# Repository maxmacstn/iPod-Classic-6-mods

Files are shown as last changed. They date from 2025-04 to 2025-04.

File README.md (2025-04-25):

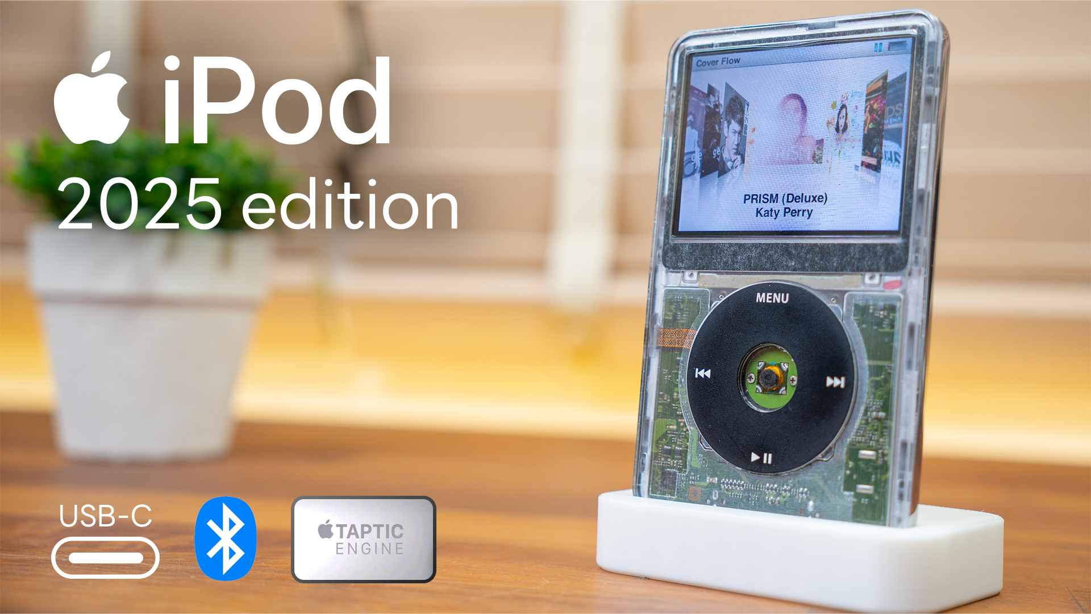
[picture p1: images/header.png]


# iPod Classic Mods
My attempt at modernizing the iPod Classic (6th generation) includes the following:

- [USB-C Mod](https://github.com/maxmacstn/iPod-Classic-6-mods/tree/main/Mods/USB-C) – Converts the 30-pin dock connector to a USB-C interface.

- [Bluetooth Audio Mod](https://github.com/maxmacstn/iPod-Classic-6-mods/tree/main/Mods/ESP32-Bluetooth-Audio) – Enables audio transmission to headphones or speakers via Bluetooth, with playback control.

- Taptic Engine – Replaces the clicking sound (from the buzzer) with haptic feedback. There are a bunch of videos out there on how to do this mod, so I haven’t included it in this repo. I used a Taptic Engine from an iPhone 11 Plus. It's small and provides a nice, firm vibration.

Click the link above to see the details.

### Video : [**Youtube (TH)**](https://youtu.be/0jGxkwJ26Vk)

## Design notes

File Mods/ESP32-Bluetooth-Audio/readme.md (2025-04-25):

# Bluetooth Audio Mod
The iPod Classic does not have any built-in radio. The only way to listen to music is by physically connecting to the 3.5mm audio jack or the dock connector.

For the Bluetooth mod, people usually use off-the-shelf Bluetooth transmitter modules connected to the headphone output. This method works, but the audio quality isn't the best, and you can't control playback via Bluetooth headphones or speakers.

Instead of using an off-the-shelf Bluetooth transmitter module, I made my own Bluetooth board for this purpose. The main controller is an ESP32.

## Version 1 - Music via I2S
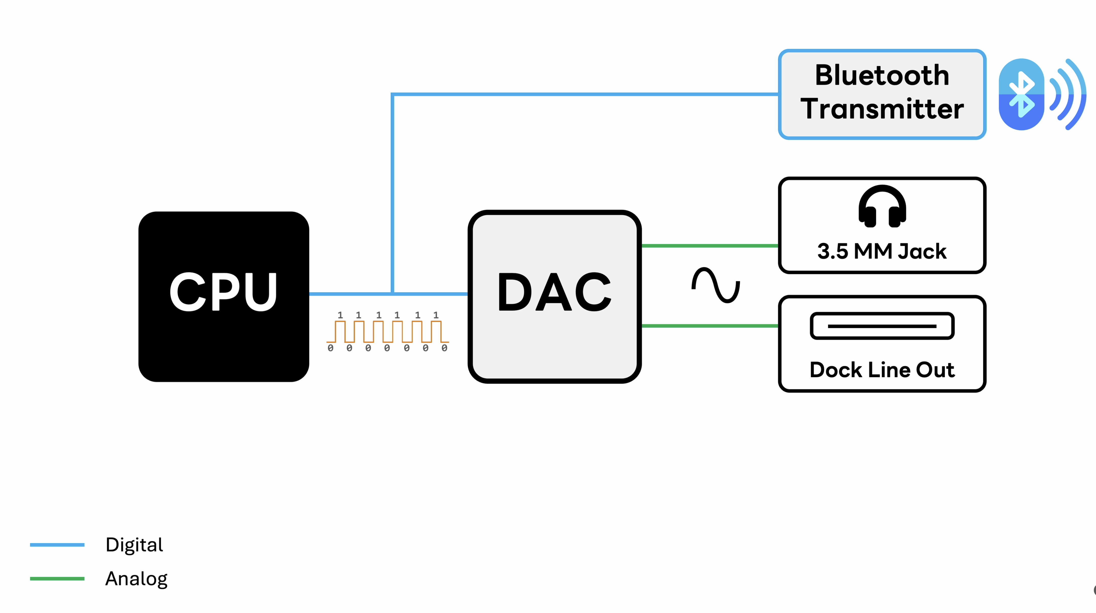
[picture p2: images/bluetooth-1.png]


When the iPod produces sound, it sends a digital audio signal from the CPU to the DAC via the I2S protocol. The digital signal is then converted into an analog signal, which is the sound we hear through headphones. To preserve the original sound quality, tapping into the I2S signal is the way to go.

I didn’t coin the idea of hijacking the I2S signal from the iPod. I found [this really cool project](https://github.com/lemonjesus/iPodBluetooth) by @lemonjesus, where he successfully did this with his iPod Nano 3rd gen. I wanted to apply this concept to my iPod Classic 6th gen as well.

From my research, the iPod Classic 6th gen uses a DAC from Cirrus Logic — allegedly the CS42L55. I checked the pinout from the datasheet, and it matches.

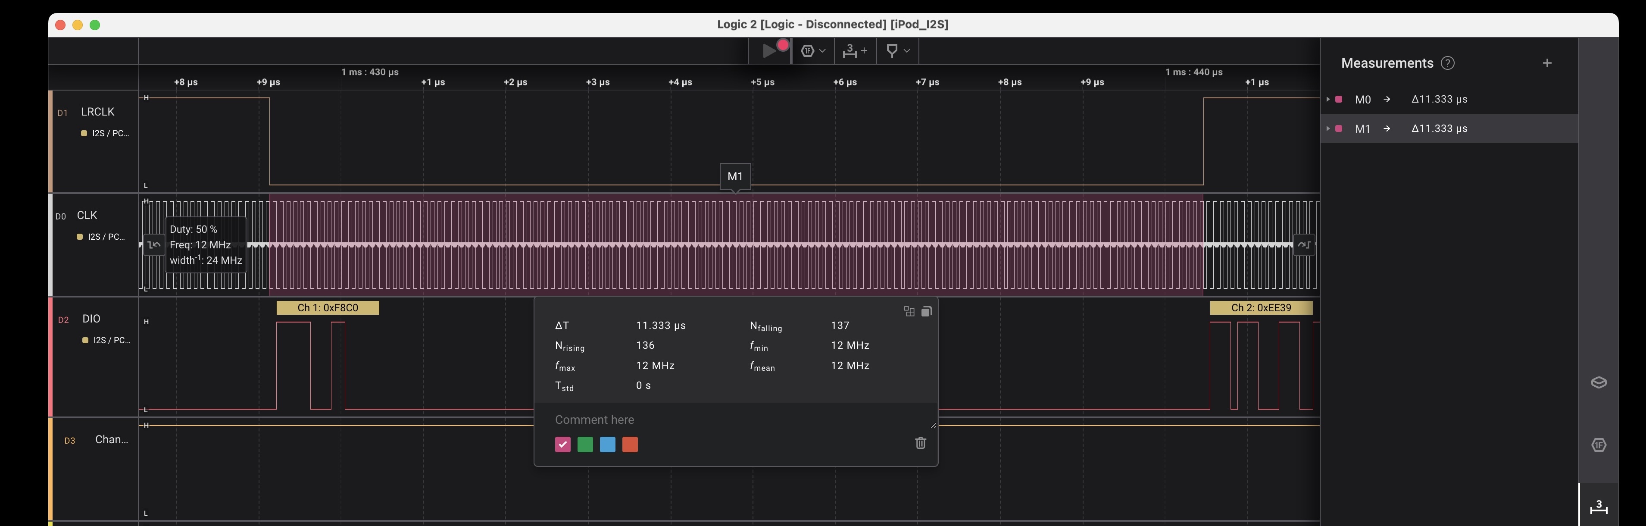
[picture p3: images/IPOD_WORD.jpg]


Long story short, this version of the iPod uses a not-so-standard I2S protocol. While the signal is technically I2S, the BCLK line runs at a very high speed (12 MHz) and also acts as MCLK. The word length is also not 16-bit. After months of trying, I wasn’t able to get it working properly with the ESP32. I gave up using I2S as the audio source from the iPod Classic.

However, I bought a Nano 3rd gen, and my Bluetooth board works as expected with it.

## Version 2 - Music via Line Out
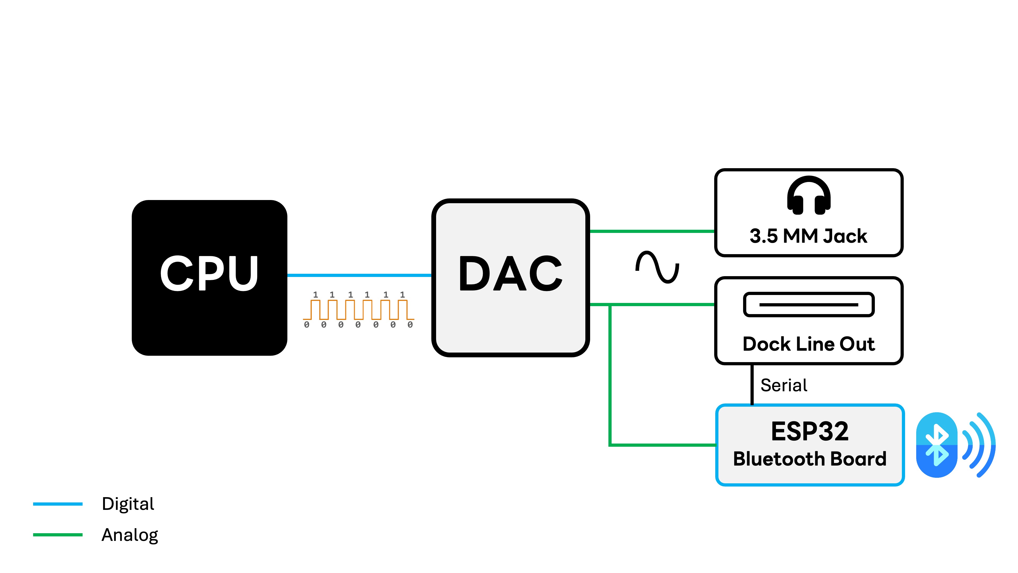
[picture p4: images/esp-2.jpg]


### Design 
Instead of using I2S, I used the line-out signal from the dock connector. The analog audio signal from the line-out is converted back to digital I2S using an ADC—specifically the PCM1860.

For playback control, external accessories can control the iPod via the dock connector using a serial protocol. There are a bunch of [examples online](https://github.com/finsprings/arduinaap). I’ve already prepared breakout pads for both the line-out and serial connections from the USB-C mod.

### Sound Quality
Definitely not as good as the original source since the audio goes through double conversion. I would say the sound quality is neither great nor terrible — it's acceptable. When listening through high-quality headphones or speakers, I can hear very subtle digital noise from interference. I even tried connecting the line-out directly from the DAC IC, but the noise was still there. So, I applied a simple filter: if the signal amplitude is very low, I set it to zero. I think this is good enough. The noise is mostly inaudible when music is playing.

### Power
I soldered the VBATT line after it passes through the power management IC. As a result, it's powered off along with the iPod. However, it doesn’t sleep when the iPod sleeps. So I implemented a check on the audio signal — if it's silent for five minutes, the Bluetooth board goes into deep sleep. There is still a small current draw, which drains the iPod’s battery in a few days. Initially, I used the 1.8V bus to enable the ESP32's power regulator, but that method stopped working for some reason, and I’ve been too lazy to fix it.

The original battery gives around 2 hours of Bluetooth music playback. This is just a proof of concept, and the battery life isn’t great.

### Bluetooth usage
I intended to not modify any sofware on the iPod, so how I could pair bluetooth device from the iPod, here's the step.
1. Restart the iPod by holding `SELECT` + `MENU`. This cuts off the power to the iPod, as well as the bluetooth board.
2. Once connected to the power, the bluetooth board starts discovering bluetooth audio device, then connected to the nearest (strongest signal) one.
3. Enjoy the music via bluetooth.
4. If there's no audio for 5 minutes, the Bluetooth board (ESP32) goes into deep sleep—until power is cut and reconnected.

### Signal
The iPod Classic has a metal front and back plate, which basically makes it a Faraday cage — signal can’t pass through easily. I removed the metal support underneath the display, which allows the signal to pass through a bit, but the range is still very limited (<1m). This could be easily fixed by 3D printing a plastic back cover—but that’s for later.

***TBC***

### Images



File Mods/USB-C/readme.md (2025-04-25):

# USB-C Mod
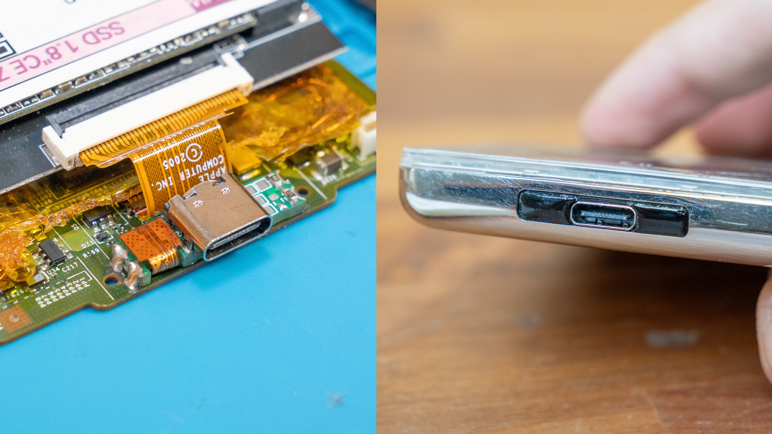
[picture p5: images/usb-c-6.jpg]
image info


## Why
As we know, the 30-pin dock connector is an outdated interface that's no longer commonly used. This mod replaces the dock connector with a USB-C port. Keep in mind that you'll lose support for other dock connector features and won't be able to use 30-pin accessories anymore. For me, the convenience of USB-C makes it a no-brainer.

## Design

The dock connector is ancient. How it works is each pin has a specific purpose, e.g. USB, FireWire, line out, serial, etc. Therefore, it has many pins. What I did was tap into the USB D+, D−, VCC, and GND from the dock connector and connect them to a USB-C port. Seems simple, doesn't it?

However, the depth of the USB-C port is longer than the 30-pin dock connector. The PCB part that holds the USB-C port sits over the dock connector solder pads. What I did was create two parts: a solid PCB and a flexible PCB. The solid PCB holds the USB-C connector as well as attaches the PCB itself to the iPod's circuit board. The flexible PCB, aka FPC, connects the corresponding pins from the dock connector solder pads to the solid PCB. The FPC bends 180° to connect to the PCB using a Molex mezzanine connector. Don't forget to put some tape on the bottom of the PCB to avoid shorting to the dock connector pads.

The PCB includes three 0603 resistors—two for enabling charging with USB-C PD adapters, and one (optional) for iPod accessory identification. Additionally, there are four soldering pads connected to the dock connector: Line_L, Line_R (for audio line out), and TX, RX (for serial communication). These are used for other mods, like the Bluetooth audio mod, which I used it.

Finally, the port bezel, attached to the iPod’s back cover, had to be replaced. I designed a new bezel for the USB-C port and 3D printed it using an FDM printer. After some sanding and painting, it now has a nice glossy finish.

## How hard if I want one?
I am not going to sell it. I have provided all the files, including the KiCad project, Gerber files, bill of materials, as well as the 3D file in this repository. If you dare to solder these tiny parts, you’ll need to fabricate them yourself through a PCB manufacturer of your choice.

I'm not a microsoldering expert, but I would say I have intermediate soldering skills. It's still quite challenging. For me, the hardest part was soldering the mezzanine connectors.

## Conclusion
USB-C works perfectly fine. It connects to the computer as well as the car's infotainment system—no issues so far. The charging function and speed are the same as the original. The Apple original charger is still needed for the iPod to display the charging icon, or you can charge via a PC.

## Images

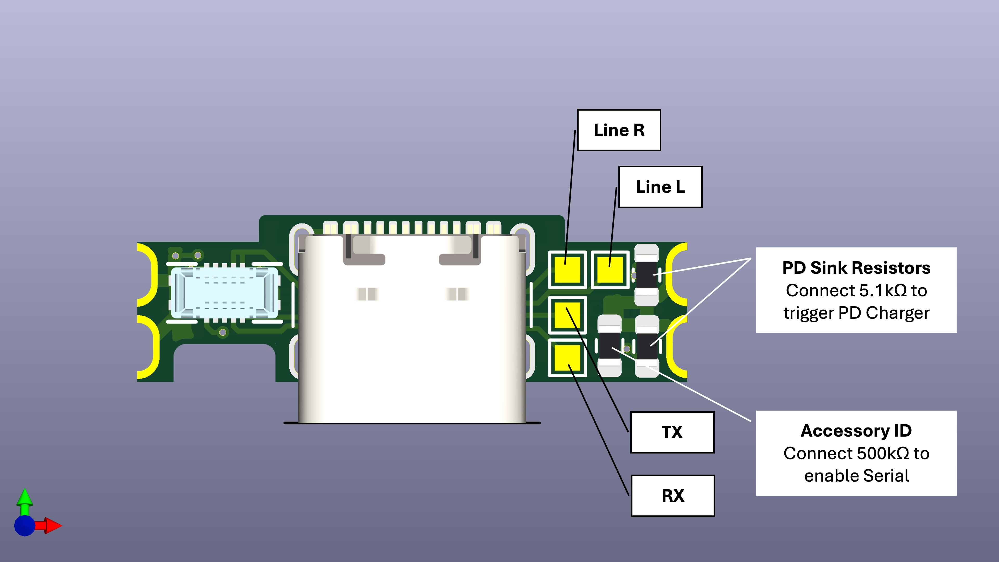
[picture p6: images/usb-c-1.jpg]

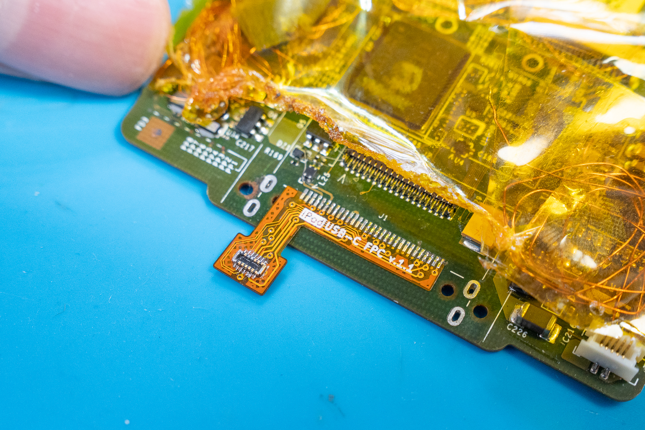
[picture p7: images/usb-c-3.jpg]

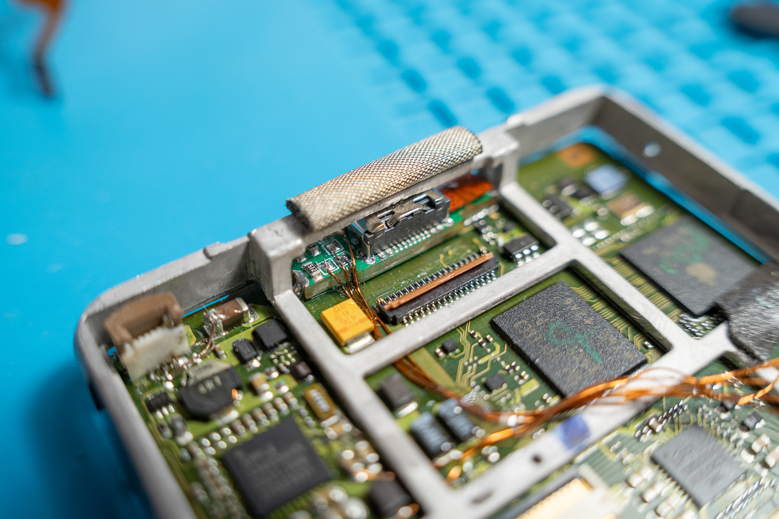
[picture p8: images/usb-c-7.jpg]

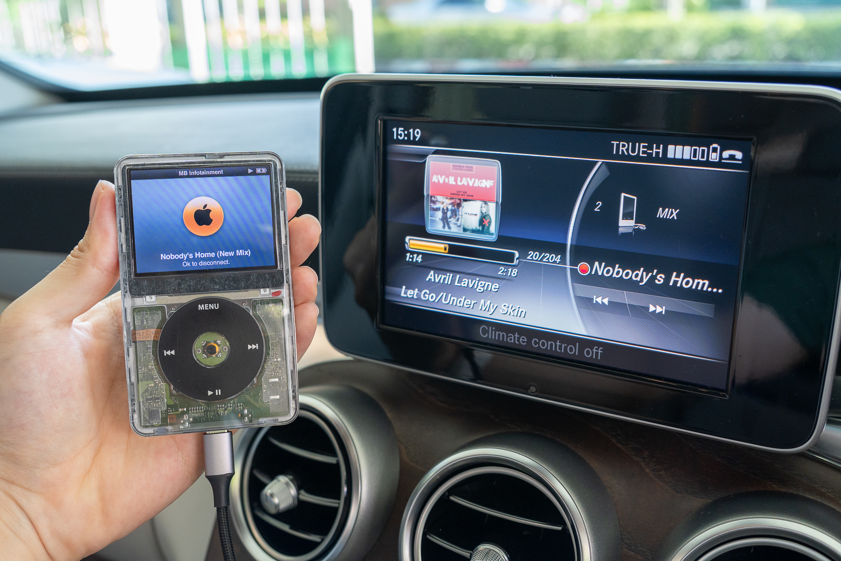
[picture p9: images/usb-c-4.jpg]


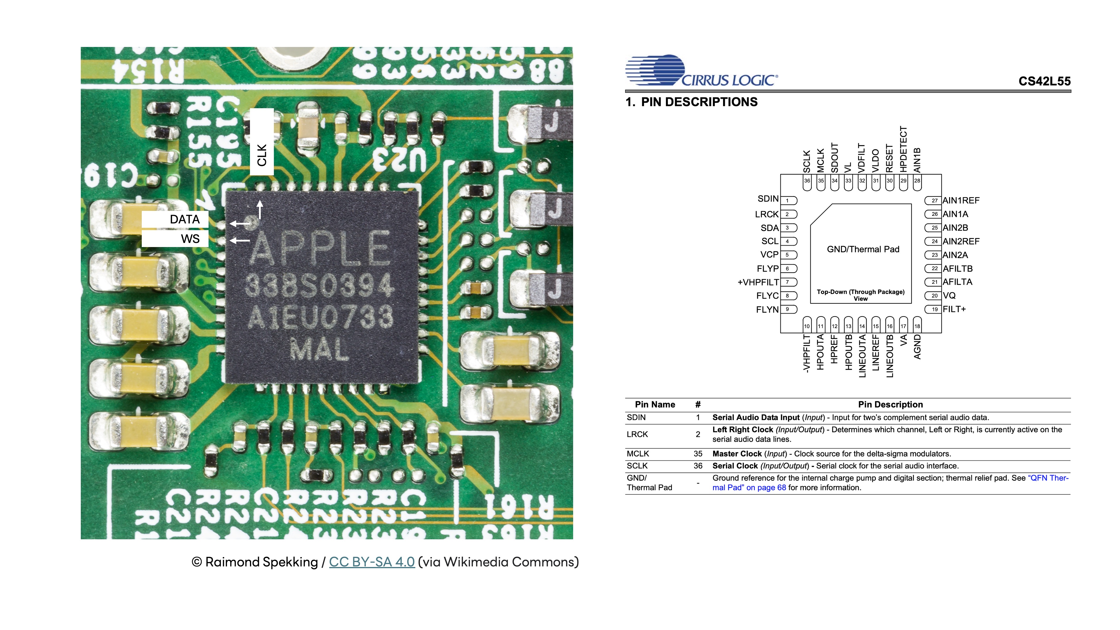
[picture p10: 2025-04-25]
images/ipod_i2s_pinout.jpg

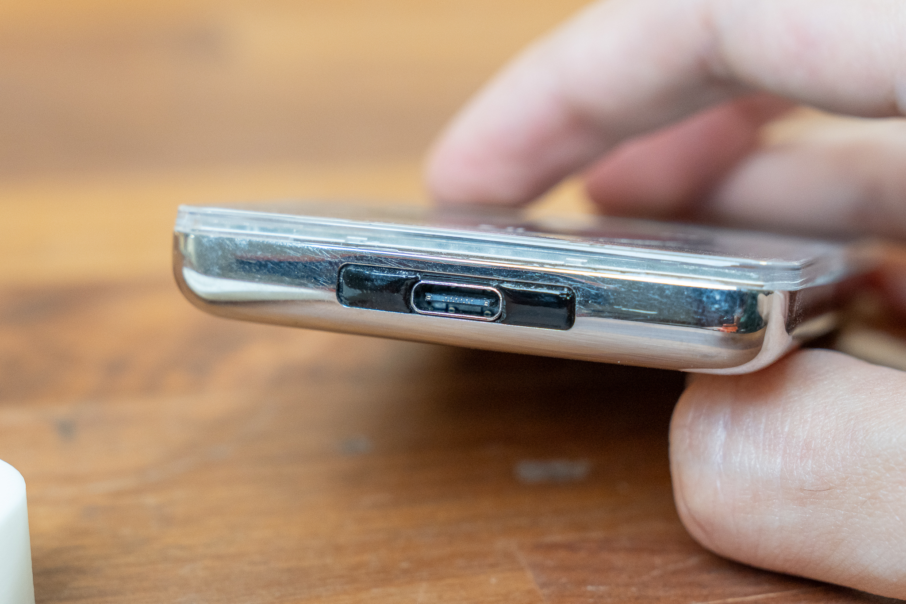
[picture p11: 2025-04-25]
images/usb-c-2.jpg

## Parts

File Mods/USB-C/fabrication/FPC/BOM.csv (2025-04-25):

Reference | Value | Datasheet | Footprint | Qty | DNP
J2 | ~ | https://www.molex.com/en-us/products/part-detail/5050701022?display=pdf | Connector_Molex:MOLEX_505070_1022 | 1

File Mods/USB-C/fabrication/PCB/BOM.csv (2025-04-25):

Reference | Value | Datasheet | Footprint | Qty | DNP
J1 | 5052701012 | 5052701012 | Connector_Molex:MOLEX_505270_1012 | 1
J2 | USB_C_Receptacle_USB2.0_16P | https://www.usb.org/sites/default/files/documents/usb_type-c.zip | Connector_USB:USB_C_Receptacle_GCT_USB4105-xx-A_16P_TopMnt_Horizontal | 1
R1,R2 | 5.1K | ~ | Resistor_SMD:R_0603_1608Metric | 2
R3 | 500K | ~ | Resistor_SMD:R_0603_1608Metric | 1
TP1 | TX | ~ | TestPoint:TestPoint_Pad_1.0x1.0mm | 1
TP2,TP3,TP4 | RX | ~ | TestPoint:TestPoint_Pad_1.0x1.0mm | 3

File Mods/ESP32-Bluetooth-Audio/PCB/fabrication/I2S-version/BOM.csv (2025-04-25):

Comment | Designator | Footprint | LCSC
0.1uF | C1,C3,C4 | Capacitor_SMD:C_0402_1005Metric | C110251
22uF | C2 | Capacitor_SMD:C_0805_2012Metric | C5674
LED | D1 | LED_SMD:LED_0603_1608Metric | C434421
Conn_01x09_Socket | J1 | Connector_JST:JST_ZH_S9B-ZR-SM4A-TF_1x09-1MP_P1.50mm_Horizontal
Conn_01x05_Socket | J2 | Connector_PinHeader_2.54mm:PinHeader_1x05_P2.54mm_Vertical
10K | R1 | Resistor_SMD:R_0402_1005Metric | C60490
1K | R2 | Resistor_SMD:R_0402_1005Metric | C106235
TLV76733DRVx | U1 | Package_SON:WSON-6-1EP_2x2mm_P0.65mm_EP1x1.6mm_ThermalVias | C2848334
ESP32-WROOM-E | U2 | PCM_Espressif:ESP32-WROOM-32E | C701341
TXU0104RUTR | U3 | Package_DFN_QFN:Texas_R-PUQFN-N12 | C5187176

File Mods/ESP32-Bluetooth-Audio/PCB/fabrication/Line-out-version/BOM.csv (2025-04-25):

Comment | Designator | Footprint | LCSC
0.1uF | C1 | Capacitor_SMD:C_0402_1005Metric | C110251
22uF | C2 | Capacitor_SMD:C_0805_2012Metric | C5674
10uF | C3,C4 | Capacitor_SMD:C_0805_2012Metric | C5674
2.2uF | C5,C6 | Capacitor_SMD:C_0402_1005Metric | C12530
15pF | C7,C8 | Capacitor_SMD:C_0402_1005Metric | C106997
LED | D1 | LED_SMD:LED_0603_1608Metric | C434421
Conn_01x09_Socket | J1 | Connector_JST:JST_ZH_S9B-ZR-SM4A-TF_1x09-1MP_P1.50mm_Horizontal
Conn_01x06_Pin | J2 | Connector_PinHeader_2.54mm:PinHeader_1x06_P2.54mm_Vertical
10K | R1 | Resistor_SMD:R_0402_1005Metric | C60490
1K | R2 | Resistor_SMD:R_0402_1005Metric | C106235
10K | RN1 | Resistor_SMD:R_Array_Convex_4x0603 | C29718
TLV76733DRVx | U1 | Package_SON:WSON-6-1EP_2x2mm_P0.65mm_EP1x1.6mm_ThermalVias | C2848334
ESP32-WROOM-E | U2 | PCM_Espressif:ESP32-WROOM-32E | C701341
PCM1860 | U3 | Package_SO:TSSOP-30_4.4x7.8mm_P0.5mm | C1520799
2N7002DW | U4 | Package_TO_SOT_SMD:SOT-363_SC-70-6 | C83571
Crystal_GND24 | Y2 | Crystal:Crystal_SMD_3225-4Pin_3.2x2.5mm | C19631429

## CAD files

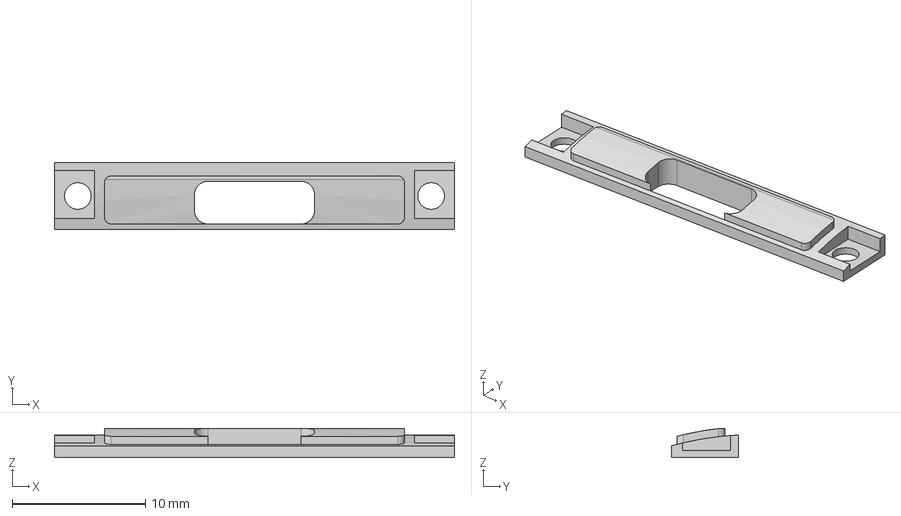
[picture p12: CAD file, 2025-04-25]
Mods/USB-C/fabrication/Port-bezel/ipod-usbc-cover-v3.step
30.0 x 5.00 x 2.20 mm

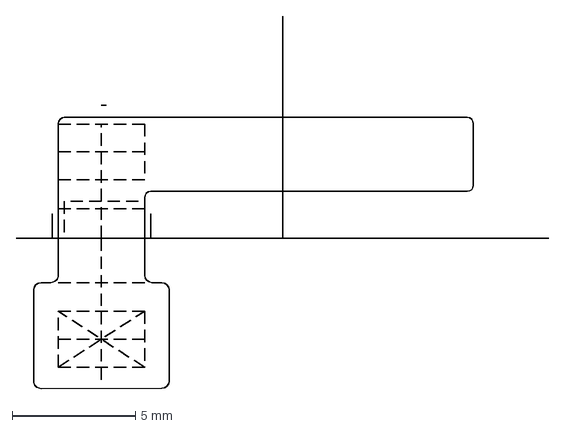
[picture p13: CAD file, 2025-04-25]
Mods/USB-C/fpc_layout.dxf
21.6 x 15.1 mm

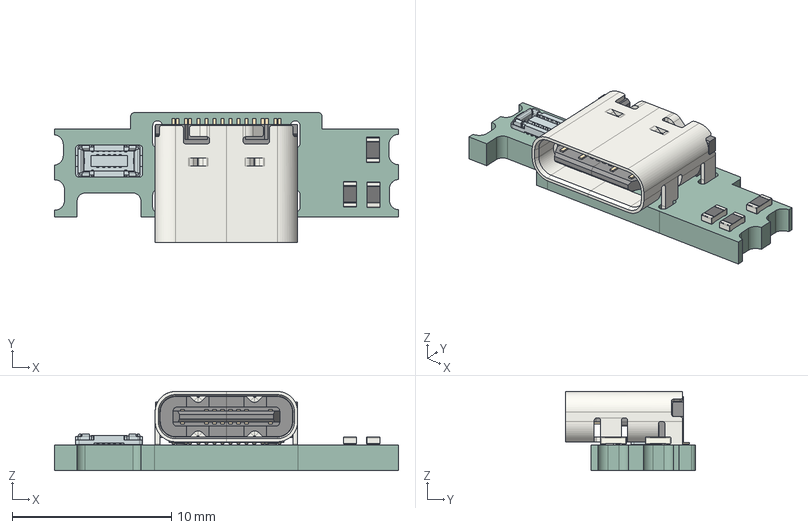
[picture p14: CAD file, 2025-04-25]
Mods/USB-C/kicad/iPod_USB-C_PCB/iPod_USB-C_PCB/iPod_USB-C_PCB.step
21.6 x 8.15 x 4.96 mm
R_0603_1608Metric x 3
USB_C_Receptacle_16P_TopMnt_Horizontal_GCT_USB4105-xx-A
5052701012wbm000_01
iPod_USB-C_PCB_PCB

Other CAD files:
Mods/USB-C/fabrication/Port-bezel/ipod-usbc-cover-v3.stl

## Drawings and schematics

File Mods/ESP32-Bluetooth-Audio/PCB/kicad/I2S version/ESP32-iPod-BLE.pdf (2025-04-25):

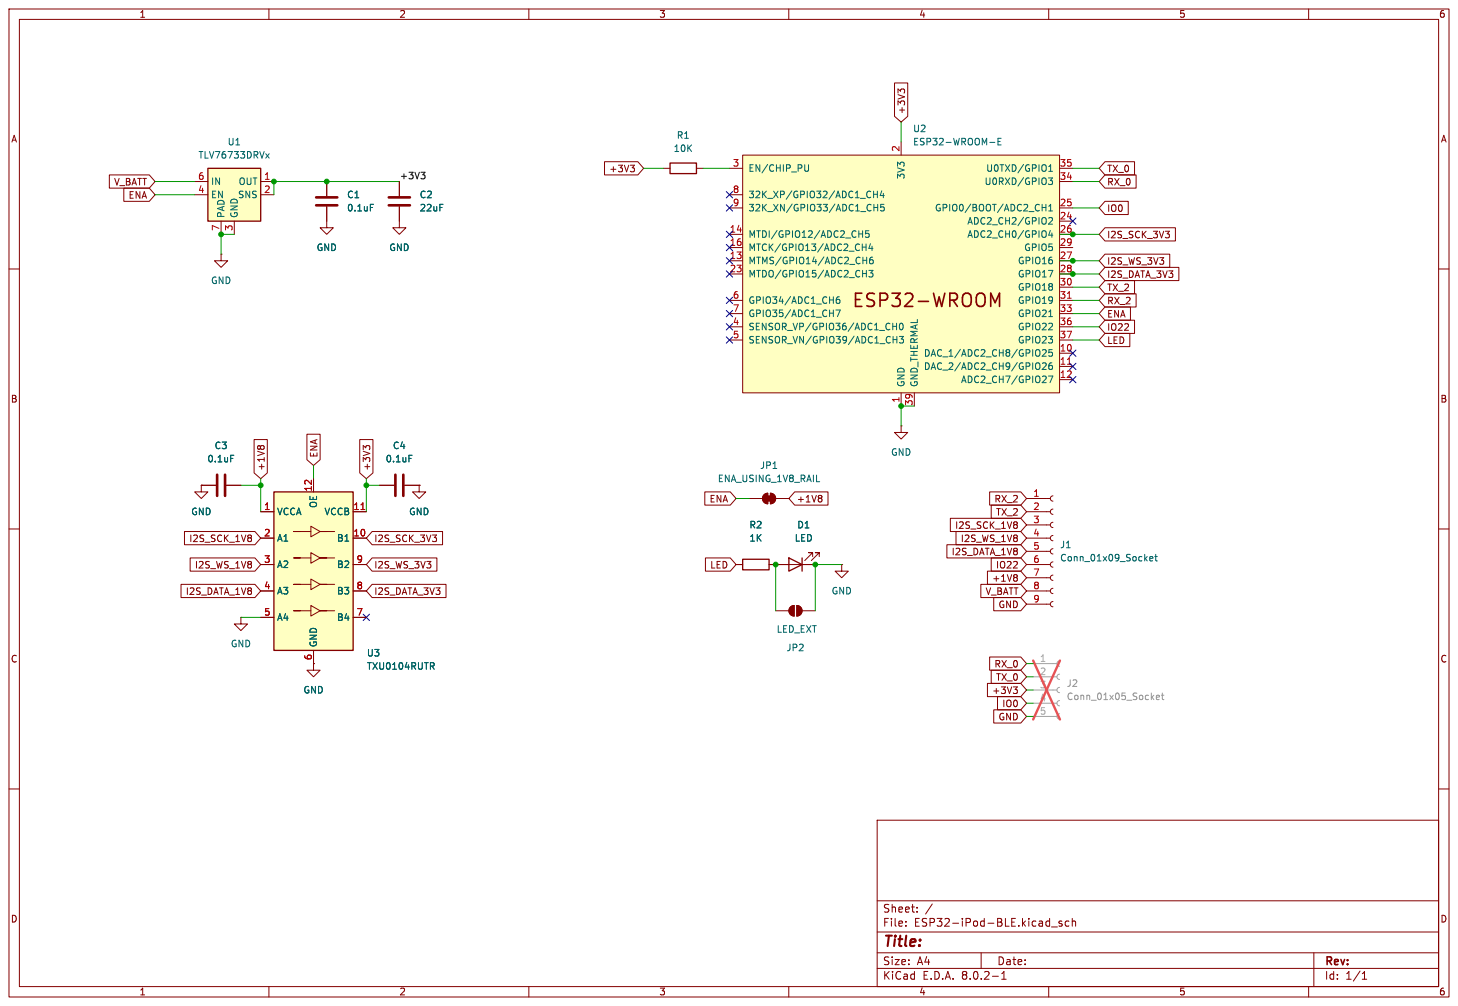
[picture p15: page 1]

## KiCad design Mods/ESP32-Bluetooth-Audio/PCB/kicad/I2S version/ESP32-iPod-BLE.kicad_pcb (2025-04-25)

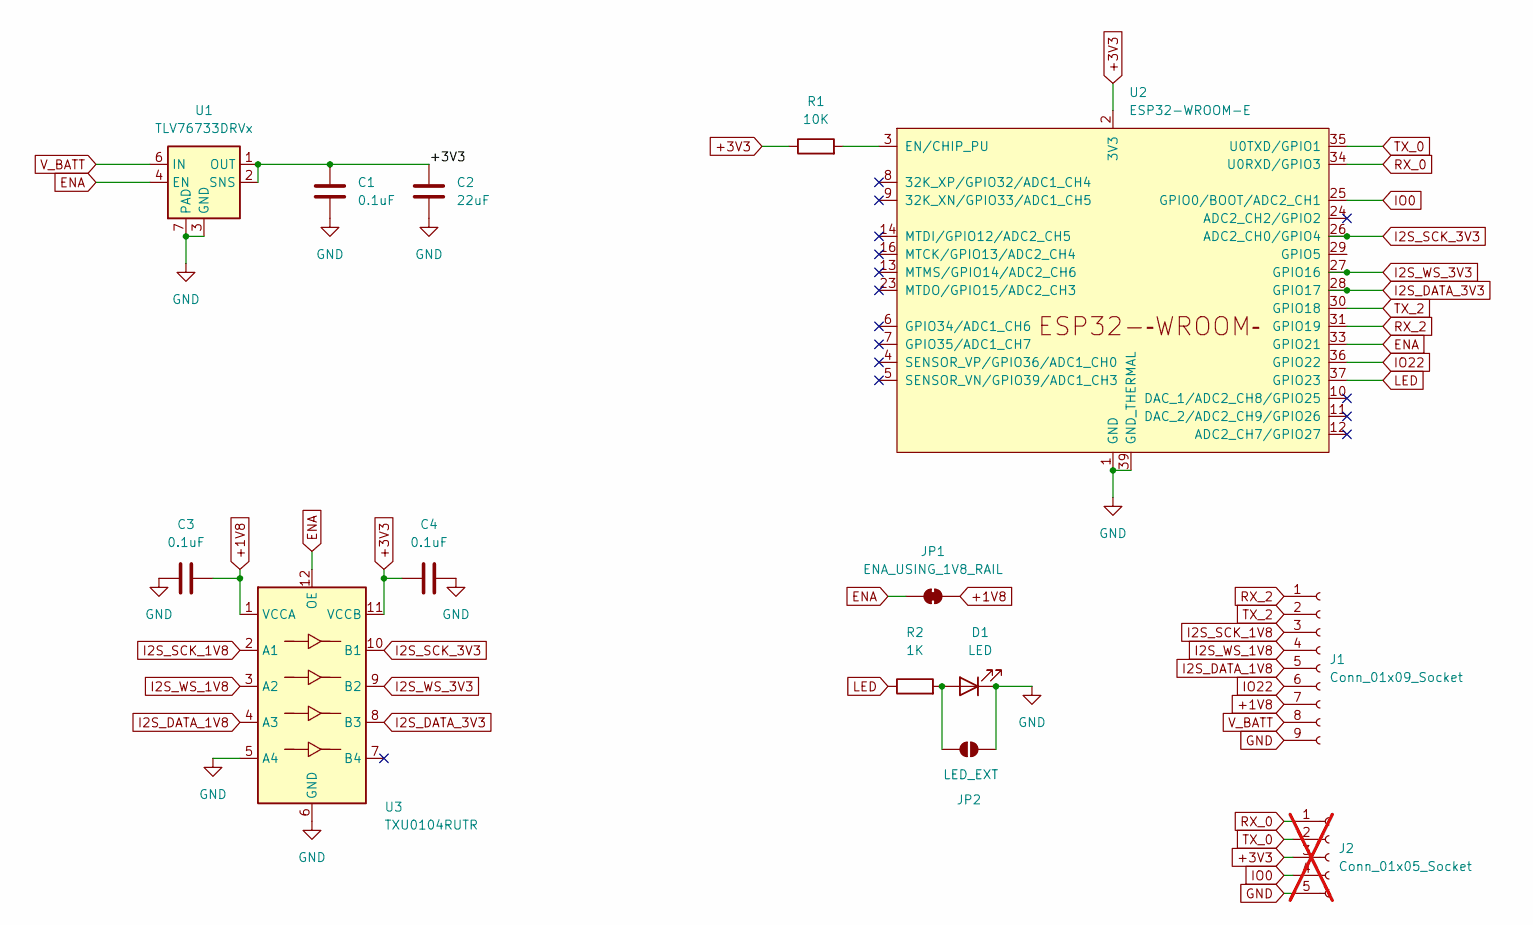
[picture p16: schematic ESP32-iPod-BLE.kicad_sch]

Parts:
C1, C3, C4: 0.1uF; C_0402_1005Metric; LCSC C110251
C2: 22uF; C_0805_2012Metric; LCSC C5674
D1: LED; LED_0603_1608Metric; LCSC C434421
J1: Conn_01x09_Socket; JST_ZH_S9B-ZR-SM4A-TF_1x09-1MP_P1.50mm_Horizontal
J2: Conn_01x05_Socket; PinHeader_1x05_P2.54mm_Vertical; not fitted
JP1: ENA_USING_1V8_RAIL; SolderJumper-2_P1.3mm_Bridged_Pad1.0x1.5mm
JP2: LED_EXT; SolderJumper-2_P1.3mm_Open_Pad1.0x1.5mm
R1: 10K; R_0402_1005Metric; LCSC C60490
R2: 1K; R_0402_1005Metric; LCSC C106235
U1: TLV76733DRVx; WSON-6-1EP_2x2mm_P0.65mm_EP1x1.6mm_ThermalVias; LCSC C2848334
U2: ESP32-WROOM-E; ESP32-WROOM-32E; LCSC C701341
U3: TXU0104RUTR; Texas_R-PUQFN-N12; LCSC C5187176

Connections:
+1V8: C3.2, J1.7, JP1.2 (B), U3.1 (VCCA)
+3V3: C1.1, C2.1, C4.1, J2.3, R1.1, U1.1 (OUT), U1.2 (SNS), U2.2 (3V3), U3.11 (VCCB)
ENA: JP1.1 (A), U1.4 (EN), U2.33 (GPIO21), U3.12 (OE)
GND: C1.2, C2.2, C3.1, C4.2, D1.1 (K), J1.9, J2.5, JP2.1 (A), U1.3 (GND), U1.5 (GND), U1.7 (PAD), U2.1 (GND), U2.15 (GND), U2.38 (GND), U2.39 (GND_THERMAL), U3.5 (A4), U3.6 (GND)
I2S_DATA_1V8: J1.5, U3.4 (A3)
I2S_DATA_3V3: U2.28 (GPIO17), U3.8 (B3)
I2S_SCK_1V8: J1.3, U3.2 (A1)
I2S_SCK_3V3: U2.26 (ADC2_CH0/GPIO4), U3.10 (B1)
I2S_WS_1V8: J1.4, U3.3 (A2)
I2S_WS_3V3: U2.27 (GPIO16), U3.9 (B2)
IO0: J2.4, U2.25 (GPIO0/BOOT/ADC2_CH1)
IO22: J1.6, U2.36 (GPIO22)
LED: R2.1, U2.37 (GPIO23)
unnamed: D1.2 (A), JP2.2 (B), R2.2
unnamed: R1.2, U2.3 (EN/CHIP_PU)
RX_0: J2.1, U2.34 (U0RXD/GPIO3)
RX_2: J1.1, U2.31 (GPIO19)
TX_0: J2.2, U2.35 (U0TXD/GPIO1)
TX_2: J1.2, U2.30 (GPIO18)
V_BATT: J1.8, U1.6 (IN)

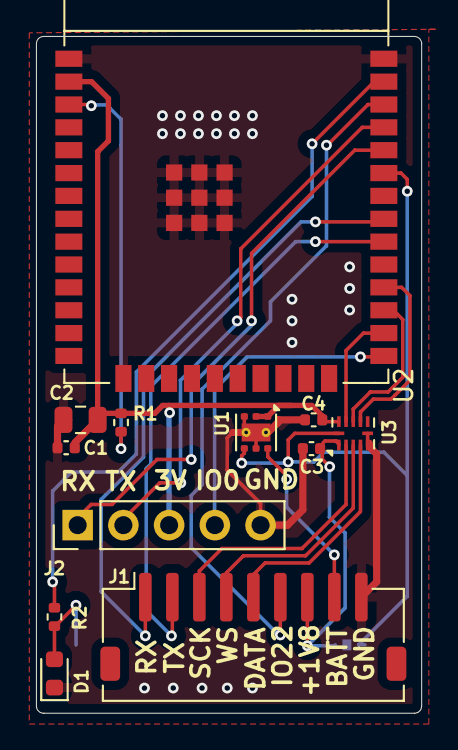
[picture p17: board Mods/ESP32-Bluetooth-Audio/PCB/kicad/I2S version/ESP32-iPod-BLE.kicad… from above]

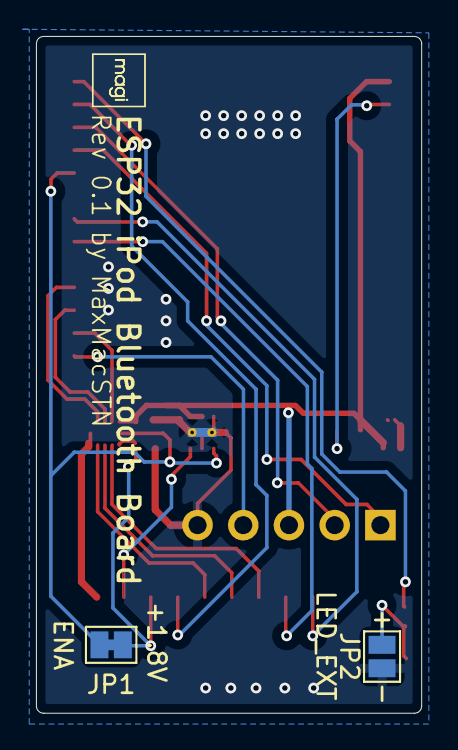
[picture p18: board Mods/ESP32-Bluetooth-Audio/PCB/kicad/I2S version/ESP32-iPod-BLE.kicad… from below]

Board: 2 copper layers, 21.4 x 37.6 mm, 14 parts (2 on the bottom side), 20 nets.

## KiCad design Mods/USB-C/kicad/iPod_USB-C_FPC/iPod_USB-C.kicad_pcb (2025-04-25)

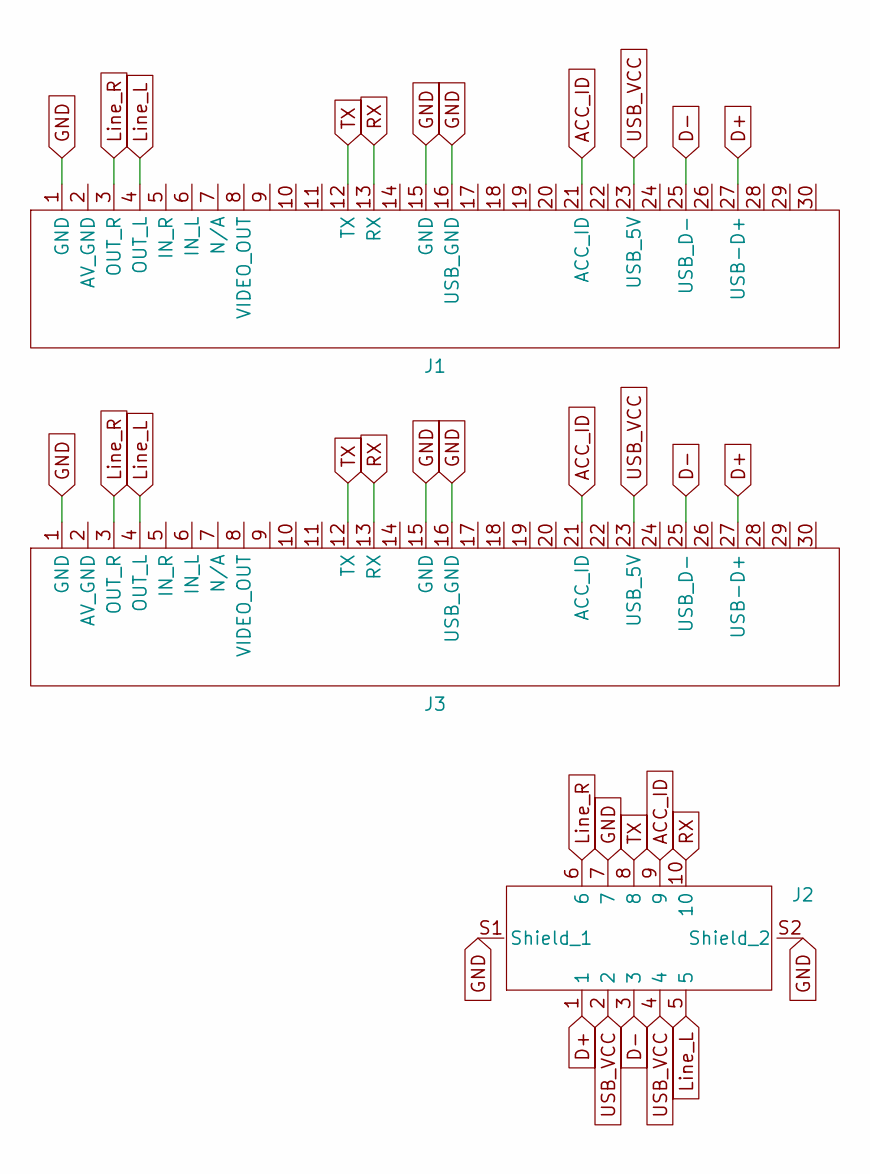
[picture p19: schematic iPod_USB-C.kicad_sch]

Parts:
J1, J3: SolderPad_iPod_Dock
J2: MOLEX_505070_1022

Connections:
ACC_ID: J1.21 (ACC_ID), J2.9, J3.21 (ACC_ID)
D+: J1.27 (USB-D+), J2.1, J3.27 (USB-D+)
D-: J1.25 (USB_D-), J2.3, J3.25 (USB_D-)
GND: J1.1 (GND), J1.15 (GND), J1.16 (USB_GND), J2.7, J2.S1 (Shield_1), J2.S2 (Shield_2), J3.1 (GND), J3.15 (GND), J3.16 (USB_GND)
Line_L: J1.4 (OUT_L), J2.5, J3.4 (OUT_L)
Line_R: J1.3 (OUT_R), J2.6, J3.3 (OUT_R)
RX: J1.13 (RX), J2.10, J3.13 (RX)
TX: J1.12 (TX), J2.8, J3.12 (TX)
USB_VCC: J1.23 (USB_5V), J2.2, J2.4, J3.23 (USB_5V)

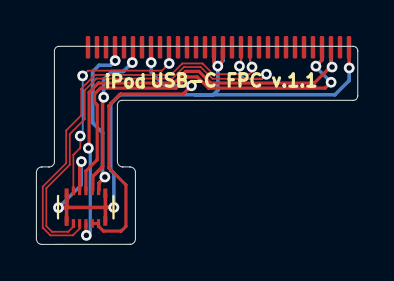
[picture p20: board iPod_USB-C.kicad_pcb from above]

Board: 2 copper layers, 17.9 x 11.0 mm, 3 parts (1 on the bottom side), 9 nets.

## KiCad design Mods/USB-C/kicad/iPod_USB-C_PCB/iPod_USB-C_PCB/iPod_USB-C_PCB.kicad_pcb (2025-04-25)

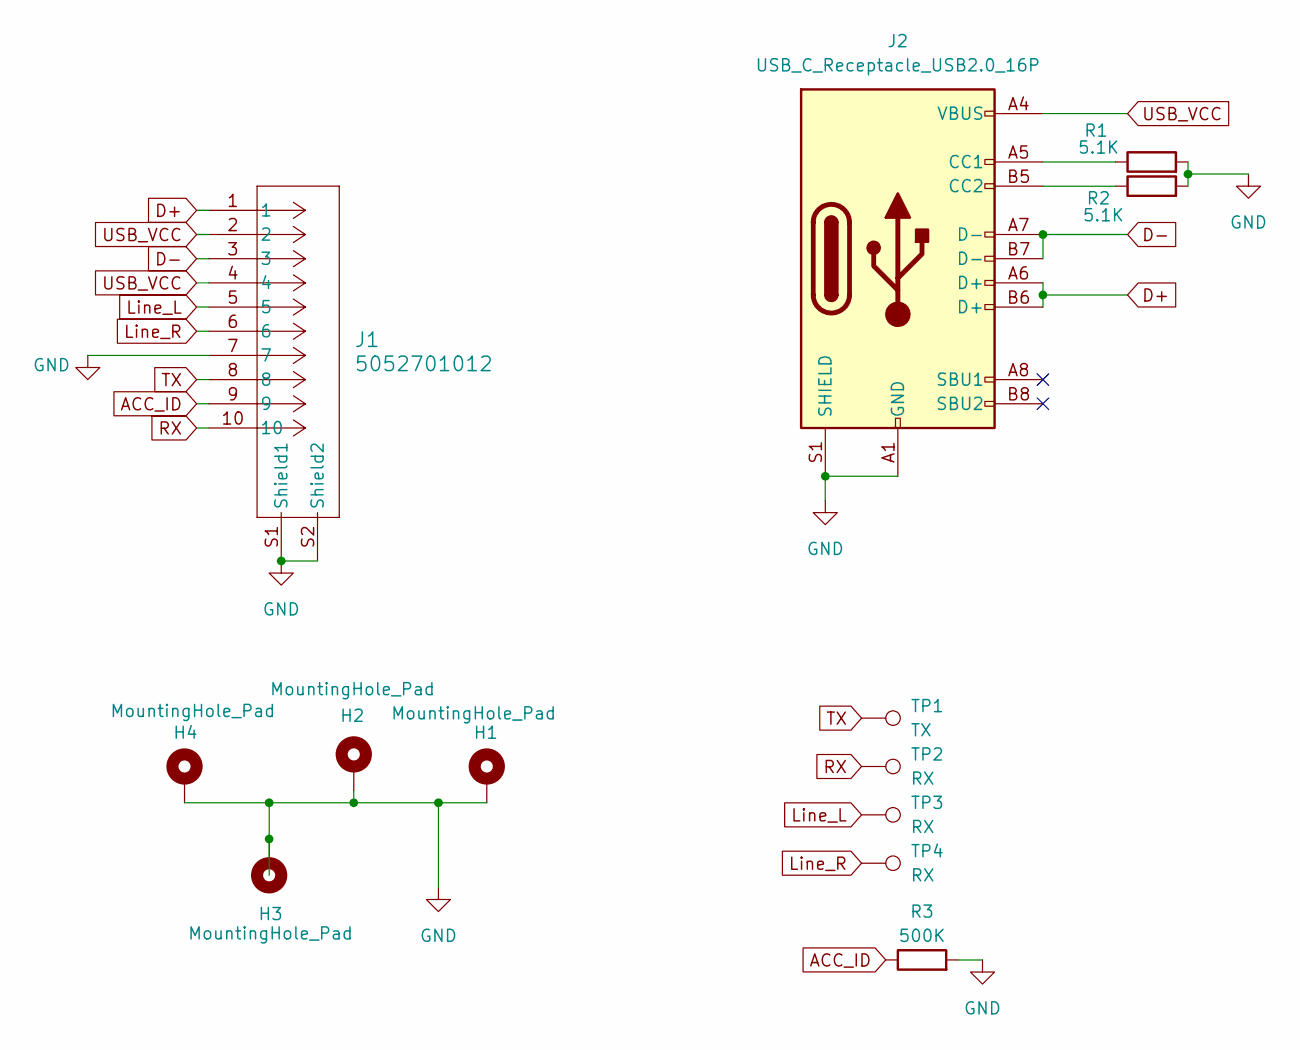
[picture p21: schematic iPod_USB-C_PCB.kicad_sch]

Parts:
H1, H2, H3, H4: MountingHole_Pad; iPod_USB-C_PCB_mount
J1: 5052701012; MOLEX_505270_1012
J2: USB_C_Receptacle_USB2.0_16P; USB_C_Receptacle_GCT_USB4105-xx-A_16P_TopMnt_Horizontal
R1, R2: 5.1K; R_0603_1608Metric
R3: 500K; R_0603_1608Metric
TP1: TX; TestPoint_Pad_1.0x1.0mm
TP2, TP3, TP4: RX; TestPoint_Pad_1.0x1.0mm

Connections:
ACC_ID: J1.9, R3.1
D+: J1.1, J2.A6 (D+), J2.B6 (D+)
D-: J1.3, J2.A7 (D-), J2.B7 (D-)
GND: H1.1, H2.1, H3.1, H4.1, J1.7, J1.S1 (Shield1), J1.S2 (Shield2), J2.A1 (GND), J2.A12 (GND), J2.B1 (GND), J2.B12 (GND), J2.S1 (SHIELD), R1.2, R2.2, R3.2
Line_L: J1.5, TP3.1
Line_R: J1.6, TP4.1
unnamed: J2.A5 (CC1), R1.1
unnamed: J2.B5 (CC2), R2.1
RX: J1.10, TP2.1
TX: J1.8, TP1.1
USB_VCC: J1.2, J1.4, J2.A4 (VBUS), J2.A9 (VBUS), J2.B4 (VBUS), J2.B9 (VBUS)

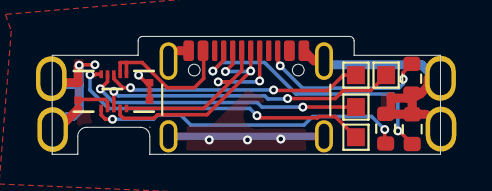
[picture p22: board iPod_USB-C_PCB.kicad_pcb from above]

Board: 2 copper layers, 21.6 x 6.5 mm, 13 parts (0 on the bottom side), 11 nets.

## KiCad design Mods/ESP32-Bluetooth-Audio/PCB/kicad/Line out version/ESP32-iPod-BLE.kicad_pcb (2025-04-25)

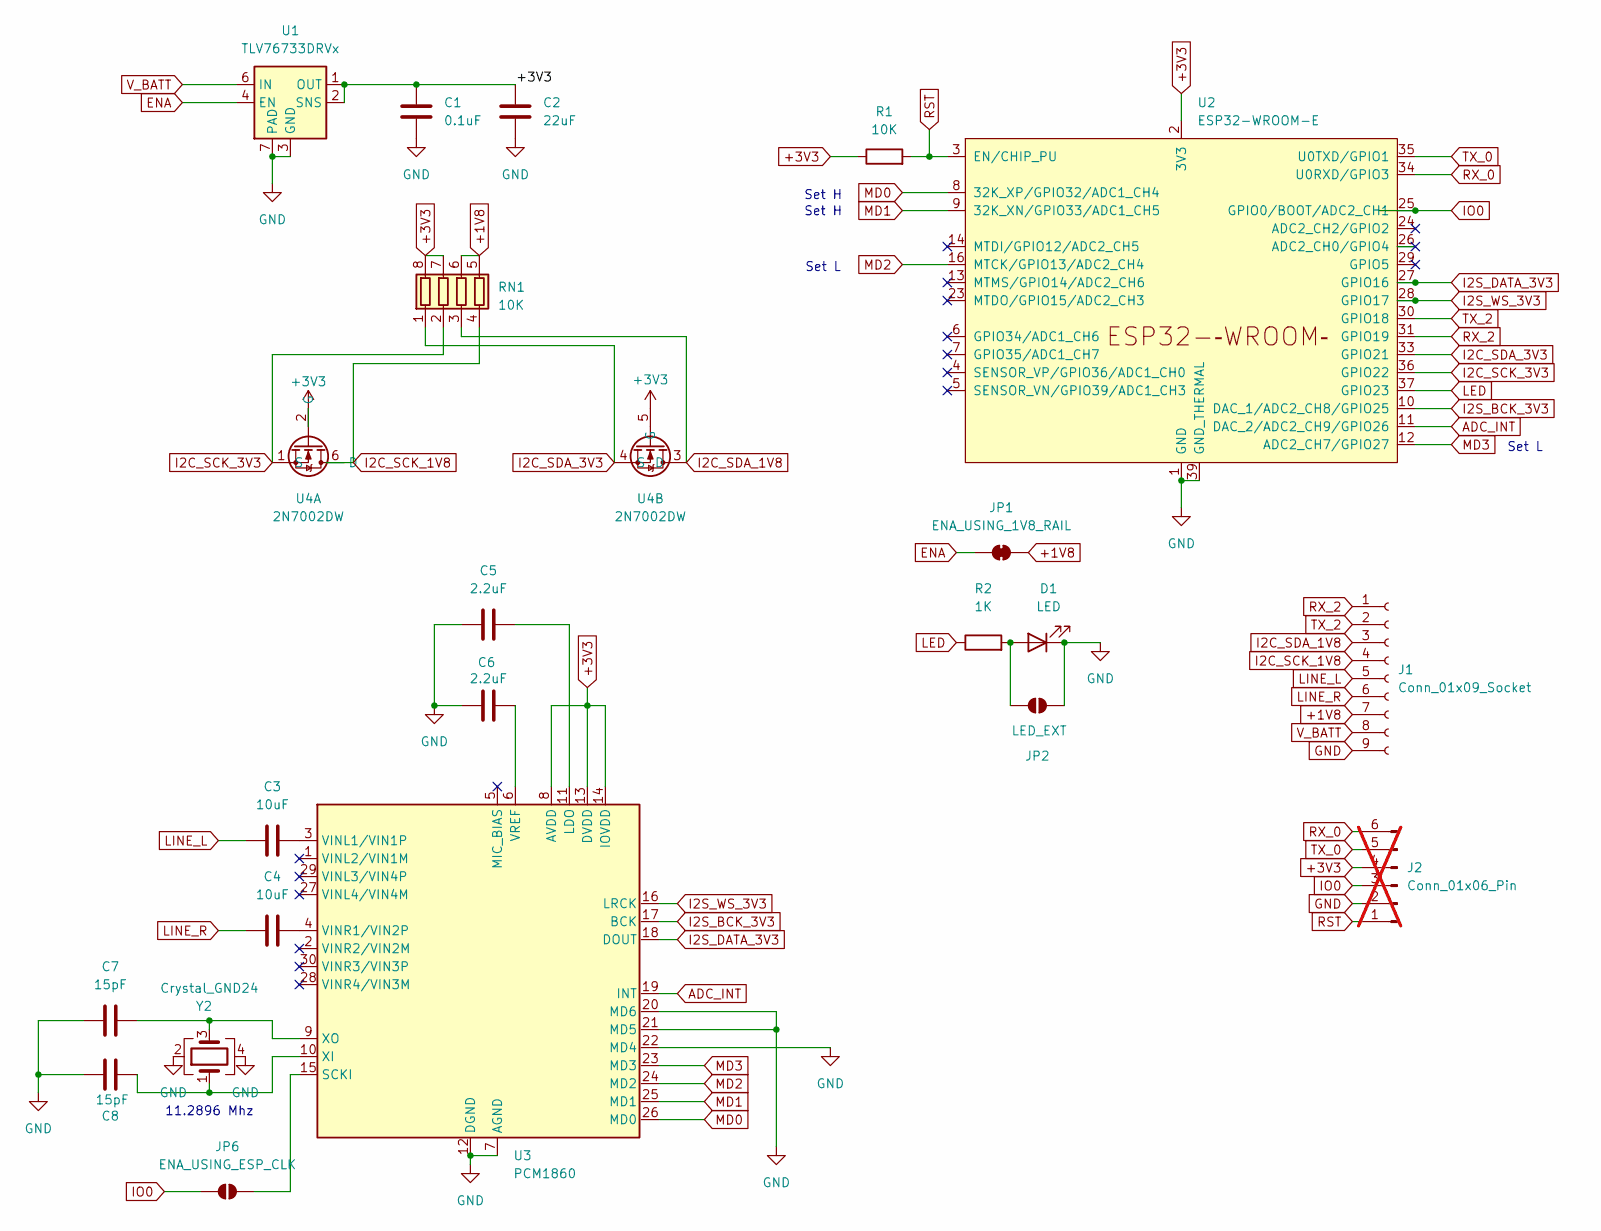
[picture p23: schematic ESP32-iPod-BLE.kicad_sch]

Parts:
C1: 0.1uF; C_0402_1005Metric; LCSC C110251
C2: 22uF; C_0805_2012Metric; LCSC C5674
C3, C4: 10uF; C_0805_2012Metric; LCSC C1713
C5, C6: 2.2uF; C_0402_1005Metric; LCSC C12530
C7, C8: 15pF; C_0402_1005Metric; LCSC C106997
D1: LED; LED_0603_1608Metric; LCSC C434421
J1: Conn_01x09_Socket; JST_ZH_S9B-ZR-SM4A-TF_1x09-1MP_P1.50mm_Horizontal
J2: Conn_01x06_Pin; PinHeader_1x06_P2.54mm_Vertical; not fitted
JP1: ENA_USING_1V8_RAIL; SolderJumper-2_P1.3mm_Bridged_Pad1.0x1.5mm
JP2: LED_EXT; SolderJumper-2_P1.3mm_Open_Pad1.0x1.5mm
JP6: ENA_USING_ESP_CLK; SolderJumper-2_P1.3mm_Open_RoundedPad1.0x1.5mm
R1: 10K; R_0402_1005Metric; LCSC C60490
R2: 1K; R_0402_1005Metric; LCSC C106235
RN1: 10K; R_Array_Convex_4x0603; LCSC C29718
U1: TLV76733DRVx; WSON-6-1EP_2x2mm_P0.65mm_EP1x1.6mm_ThermalVias; LCSC C2848334
U2: ESP32-WROOM-E; ESP32-WROOM-32E; LCSC C701341
U3: PCM1860; TSSOP-30_4.4x7.8mm_P0.5mm; LCSC C1520799
U4: 2N7002DW; SOT-363_SC-70-6; LCSC C83571
Y2: Crystal_GND24; Crystal_SMD_3225-4Pin_3.2x2.5mm; LCSC C654945

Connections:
+1V8: J1.7, JP1.2 (B), RN1.5 (R4.2), RN1.6 (R3.2)
+3V3: C1.1, C2.1, J2.4, R1.1, RN1.7 (R2.2), RN1.8 (R1.2), U1.1 (OUT), U1.2 (SNS), U2.2 (3V3), U3.8 (AVDD), U3.13 (DVDD), U3.14 (IOVDD), U4.2 (G), U4.5 (G)
ADC_INT: U2.11 (DAC_2/ADC2_CH9/GPIO26), U3.19 (INT)
ENA: JP1.1 (A), U1.4 (EN)
GND: C1.2, C2.2, C5.2, C6.1, C7.1, C8.1, D1.1 (K), J1.9, J2.2, JP2.1 (A), U1.3 (GND), U1.5 (GND), U1.7 (PAD), U2.1 (GND), U2.15 (GND), U2.38 (GND), U2.39 (GND_THERMAL), U3.7 (AGND), U3.12 (DGND), U3.20 (MD6), U3.21 (MD5), U3.22 (MD4), Y2.2, Y2.4
I2C_SCK_1V8: J1.4, RN1.4 (R4.1), U4.6 (D)
I2C_SCK_3V3: RN1.2 (R2.1), U2.36 (GPIO22), U4.1 (S)
I2C_SDA_1V8: J1.3, RN1.3 (R3.1), U4.3 (D)
I2C_SDA_3V3: RN1.1 (R1.1), U2.33 (GPIO21), U4.4 (S)
I2S_BCK_3V3: U2.10 (DAC_1/ADC2_CH8/GPIO25), U3.17 (BCK)
I2S_DATA_3V3: U2.27 (GPIO16), U3.18 (DOUT)
I2S_WS_3V3: U2.28 (GPIO17), U3.16 (LRCK)
IO0: J2.3, JP6.1 (A), U2.25 (GPIO0/BOOT/ADC2_CH1)
LED: R2.1, U2.37 (GPIO23)
LINE_L: C3.1, J1.5
LINE_R: C4.1, J1.6
MD0: U2.8 (32K_XP/GPIO32/ADC1_CH4), U3.26 (MD0)
MD1: U2.9 (32K_XN/GPIO33/ADC1_CH5), U3.25 (MD1)
MD2: U2.16 (MTCK/GPIO13/ADC2_CH4), U3.24 (MD2)
MD3: U2.12 (ADC2_CH7/GPIO27), U3.23 (MD3)
unnamed: D1.2 (A), JP2.2 (B), R2.2
unnamed: JP6.2 (B), U3.15 (SCKI)
unnamed: C5.1, U3.11 (LDO)
unnamed: C3.2, U3.3 (VINL1/VIN1P)
unnamed: C4.2, U3.4 (VINR1/VIN2P)
unnamed: C6.2, U3.6 (VREF)
unnamed: C8.2, U3.10 (XI), Y2.1
unnamed: C7.2, U3.9 (XO), Y2.3
RST: J2.1, R1.2, U2.3 (EN/CHIP_PU)
RX_0: J2.6, U2.34 (U0RXD/GPIO3)
RX_2: J1.1, U2.31 (GPIO19)
TX_0: J2.5, U2.35 (U0TXD/GPIO1)
TX_2: J1.2, U2.30 (GPIO18)
V_BATT: J1.8, U1.6 (IN)

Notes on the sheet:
Set L
Set H
11.2896 Mhz

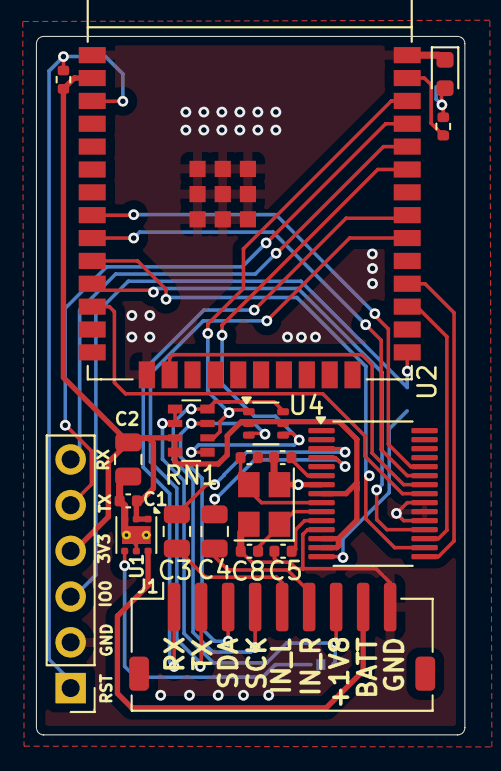
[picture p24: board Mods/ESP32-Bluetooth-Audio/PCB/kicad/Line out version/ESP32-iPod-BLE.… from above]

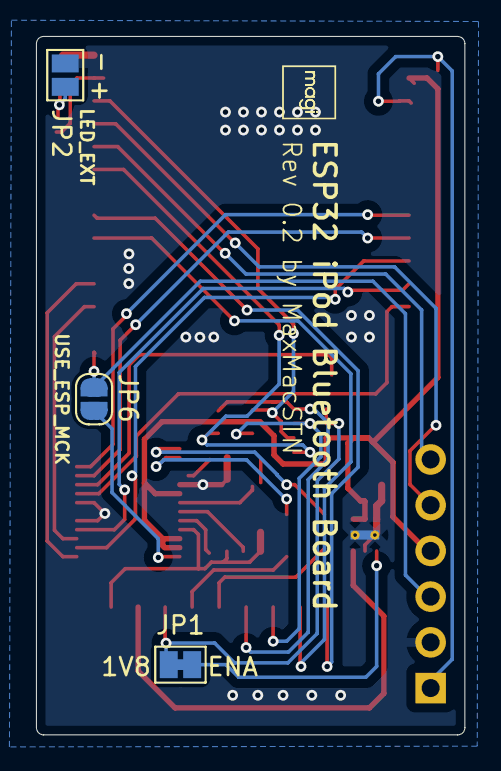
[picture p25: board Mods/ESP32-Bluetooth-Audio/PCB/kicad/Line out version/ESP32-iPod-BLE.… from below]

Board: 2 copper layers, 23.8 x 38.8 mm, 22 parts (3 on the bottom side), 34 nets.

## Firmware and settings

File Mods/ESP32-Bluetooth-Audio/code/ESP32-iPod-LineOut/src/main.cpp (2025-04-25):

#include "BluetoothA2DPSource.h"
#include "AudioTools.h"

#include "AudioTools/AudioLibs/A2DPStream.h"

I2SStream i2sStream;   // Access I2S as stream
A2DPStream a2dpStream; // access A2DP as stream

// I2S Config
static const int i2s_num = 0; // i2s port number

#define I2S_PIN_BCK         25
#define I2S_PIN_WS          17
#define I2S_PIN_DATA        16
#define LED_PIN 23
#define ADC_INT 26
#define ADC_MD_0 32
#define ADC_MD_1 33
#define ADC_MD_2 13
#define ADC_MD_3 27
#define TX_IPOD 19
#define RX_IPOD 18

// Stream Setting
#define I2S_SAMPLE_RATE 44100
#define I2S_BIT_RATE I2S_BITS_PER_SAMPLE_16BIT
#define I2S_PORT I2S_NUM_0

//Bluetooth Class of Device filter
#define BLUETOOTH_COD_MASK 0xFFF000
#define BLUETOOTH_COD_AUDIO 0x240000

//Timing
#define BLUETOOTH_SEARCH_TIME 15      //Search for bluetooth headphones for 15s
#define BLUETOOTH_CONNECTION_TIME 80  //The device must be able to connect to headphone within 60s, otherwise sleep.
#define AUDIO_INACTIVE_SLEEP_TIME 5*60    //If the audio is inactive for 5 minutes, then sleep.

StreamCopy copier(a2dpStream, i2sStream); // copies sound to out

// Task & Queues
QueueHandle_t pt_event_queue;
TaskHandle_t ipod_control_task_handle = NULL;
volatile bool isAudioActive = false;
unsigned long bluetoothSearchStartTime ;

//Prototypes
void bluetoothButtonHandler(uint8_t id, bool isReleased);
void setupBluetooth();
void notifyiPodBluetoothConnected();
void checkDeepSleep(bool isAudioActive);

uint8_t buffer[2048];
int16_t *samples = (int16_t*) buffer;

hw_timer_t *connectionMonitorTimer = NULL;

void IRAM_ATTR checkConnection(){
  static bool LEDState = 1;
  bool isBluetoothConnected = a2dpStream.source().is_connected();
  Serial.printf("Bluetooth is %s\n", isBluetoothConnected?"connected":"not connected");

  if (!isBluetoothConnected && millis() - bluetoothSearchStartTime > BLUETOOTH_CONNECTION_TIME*1000){
    //Could not connect in time, sleep the ESP.
    Serial.println("Could not connect to headphones/speakers, sleep.");
    esp_deep_sleep_start();
  }

  //Set LED
  if(isBluetoothConnected){
    digitalWrite(LED_PIN, HIGH);
  }else{
    digitalWrite(LED_PIN, LEDState);
    LEDState = !LEDState;
  }
}


//Bluetooth
struct BluetoothDeviceFound
{
  String ssid;
  esp_bd_addr_t address;
  int rssi;
};

BluetoothDeviceFound foundDevices[10];
int totalFound = 0;
int minRssi = -999;
esp_bd_addr_t minRssiMac;



// Arduino Setup
void setup(void)
{
  pinMode(LED_PIN, OUTPUT);

  for (int i = 0 ; i < 20; i++){
    digitalWrite(LED_PIN, i%2);
    delay(1000);
  }

  Serial.begin(115200);
  Serial2.begin(19200,SERIAL_8N1,RX_IPOD, TX_IPOD);
  // AudioToolsLogger.begin(Serial, AudioToolsLogLevel::Info);


  pinMode(ADC_MD_0,OUTPUT);
  pinMode(ADC_MD_1,OUTPUT);
  pinMode(ADC_MD_2,OUTPUT);
  pinMode(ADC_MD_3,OUTPUT);

  digitalWrite(ADC_MD_0,LOW);
  digitalWrite(ADC_MD_1,LOW);
  digitalWrite(ADC_MD_2,LOW);
  digitalWrite(ADC_MD_3,LOW);


  // start i2s input with default configuration
  setupBluetooth();
  Serial.println("starting I2S...");
  // a2dpStream.addNotifyAudioChange(i2sStream); // i2s is using the info from a2dp


  i2sStream.addNotifyAudioChange(a2dpStream);

  I2SConfig i2sConfig = i2sStream.defaultConfig(RX_MODE);
  i2sConfig.pin_data = I2S_PIN_DATA;
  i2sConfig.pin_bck = I2S_PIN_BCK;
  i2sConfig.pin_ws = I2S_PIN_WS;
  i2sConfig.pin_mck = 0;
  i2sConfig.is_master = true;
  i2sConfig.use_apll = false;
  i2sConfig.auto_clear =true;
  i2sConfig.sample_rate = 44100;
  i2sConfig.bits_per_sample = I2S_BITS_PER_SAMPLE_16BIT;
  // i2sConfig.buffer_count = 16;
  // i2sConfig.buffer_size = 32;
  i2sConfig.channels = 2;
  i2sConfig.i2s_format = I2S_STD_FORMAT;

  i2sStream.begin(i2sConfig);

  Serial.println("System Ready..");

  notifyiPodBluetoothConnected();


}

// Arduino loop - copy data
void loop()
{

   size_t read = i2sStream.readBytes(buffer, 2048);
   size_t samples_read = read/sizeof(int16_t);

   
   int32_t avg =0;
   int min = INT_MAX;
   int max = INT_MIN;
   for (int i = 0 ;i < samples_read; i++){
    if (buffer[i] < min)
      min = samples[i];
    if (buffer[i] > max)
      max = samples[i];    
   }
   int diff =  max-min;
  //  Serial.printf("diff = %d\n", diff);

   if (diff < 200){
    memset(buffer, 0, sizeof buffer);
    isAudioActive = false;
  }else{
    isAudioActive = true;
  }
  
  a2dpStream.write(buffer, read);

  // copier.copy();
  checkDeepSleep(isAudioActive);

}

void checkDeepSleep(bool isAudioActive){
  static bool lastState = true;
  static unsigned long audioInactiveStartTime = 0;


  if(lastState != isAudioActive){
    // Serial.printf("Audio Active: %d\n", isAudioActive);
    if (!isAudioActive){
      audioInactiveStartTime = millis();
    }
  }

  if (!isAudioActive && millis() - audioInactiveStartTime > AUDIO_INACTIVE_SLEEP_TIME *1000){
    Serial.println("Start Deepsleep");
    esp_deep_sleep_start();
  }

  lastState = isAudioActive;
}

void notifyiPodBluetoothConnected(){
  for(int i = 0; i <3; i++){
    Serial2.write((uint8_t*)"\xFFU\x06\x02\x00\x00\x00\x00\x02\xF6\xFFU\x03\x02\x00\x00\xFB", 17);
    delay(500);
    Serial2.write((uint8_t*)"\xFFU\x06\x02\x00\x00\x00\x00\x01\xF7\xFFU\x03\x02\x00\x00\xFB", 17);
    delay(500);


  }


}

void onBluetoothConnectionChanged(esp_a2d_connection_state_t state, void *obj){
  Serial.printf("Connection State = %d\n", state);
}

bool isValid(const char* ssid, esp_bd_addr_t address, int rssi, uint32_t cod){
  BluetoothDeviceFound device;
  device.ssid = ssid;
  device.rssi = rssi;
  memcpy(device.address,address,6);

  //Filter by bluetooth CoD
  if((cod & BLUETOOTH_COD_MASK) != BLUETOOTH_COD_AUDIO)
    return false;


  Serial.printf("Found: %s, rssi %d, address %x %x %x %x %x %x, cod %x\n", device.ssid, device.rssi, device.address[5], device.address[4], device.address[3],  device.address[2], device.address[1], device.address[0], cod);


  // Exceed search period, connect if the device has the strongest RSSI.
  if(millis() - bluetoothSearchStartTime > BLUETOOTH_SEARCH_TIME *1000){
    if (memcmp(address,minRssiMac,6) == 0){
      Serial.printf("Connecting to %s\n", ssid);
      return true;

    }
    return false;
  }

  //Add device and record min rssi found.
  if (totalFound < 10){

    //If added, skip.
    for (int i = 0; i < totalFound; i++){
      if (memcmp(address,foundDevices[i].address,6) == 0){
        return false;
        }
    }

    //Add device to array.
    foundDevices[totalFound] =  device;
    if (device.rssi > minRssi){
      minRssi = device.rssi;
      memcpy(minRssiMac,address,6);
    }
    totalFound++;
  }


  
  return false;
}

void setupBluetooth(){
  // start bluetooth
  Serial.println("starting A2DP...");
  auto cfgA2DP = a2dpStream.defaultConfig(TX_MODE);
  // cfgA2DP.name = "EDIFIER W320TN";
  // cfgA2DP.name = "Echo Dot-2N5";
  cfgA2DP.name = "";
  cfgA2DP.auto_reconnect = false;
  a2dpStream.source().set_auto_reconnect(false);
  a2dpStream.source().set_ssid_callback(isValid);
  a2dpStream.source().set_avrc_passthru_command_callback(bluetoothButtonHandler);
  a2dpStream.source().set_local_name("iPod Classic");
  a2dpStream.source().start();

  // set intial volume
  a2dpStream.setVolume(0.5);

  Serial.println("Searching Bluetooth");
  bluetoothSearchStartTime = millis();

  //Set timer for connection monitor
  connectionMonitorTimer = timerBegin(0, 80, true);
  timerAttachInterrupt(connectionMonitorTimer, &checkConnection, true);
  timerAlarmWrite(connectionMonitorTimer, 1000000, true);
  timerAlarmEnable(connectionMonitorTimer); 

  a2dpStream.begin(cfgA2DP);



}


void bluetoothButtonHandler(uint8_t id, bool isReleased) {
  // key codes: https://github.com/espressif/esp-idf/blob/a82e6e63d98bb051d4c59cb3d440c537ab9f74b0/components/bt/host/bluedroid/api/include/api/esp_avrc_api.h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
  // key states: 0 = Pressed, 1 = Released
  Serial.printf("Button ID: %d Action: %d\n", id, isReleased);
  if(!isReleased) return;

  switch(id) {
    case ESP_AVRC_PT_CMD_VOL_UP:
      Serial2.write((uint8_t*)"\xFFU\x03\x02\x00\x02\xF9\xFFU\x03\x02\x00\x00\xFB", 14);
      break;
    case ESP_AVRC_PT_CMD_VOL_DOWN:
      Serial2.write((uint8_t*)"\xFFU\x03\x02\x00\x04\xF7\xFFU\x03\x02\x00\x00\xFB", 14);
      break;
    case ESP_AVRC_PT_CMD_FORWARD:
    case ESP_AVRC_PT_CMD_FAST_FORWARD:
      Serial2.write((uint8_t*)"\xFFU\x03\x02\x00\b\xF3\xFFU\x03\x02\x00\x00\xFB", 14);
      break;
    case ESP_AVRC_PT_CMD_BACKWARD:
    case ESP_AVRC_PT_CMD_REWIND:
      Serial2.write((uint8_t*)"\xFFU\x03\x02\x00\x10\xEB\xFFU\x03\x02\x00\x00\xFB", 14);
      break;
    case ESP_AVRC_PT_CMD_STOP:
      Serial2.write((uint8_t*)"\xFFU\x03\x02\x00\x80{\xFFU\x03\x02\x00\x00\xFB", 14);
      break;
    case ESP_AVRC_PT_CMD_PLAY:
      Serial2.write((uint8_t*)"\xFFU\x04\x02\x00\x00\x01\xF9\xFFU\x03\x02\x00\x00\xFB", 15);
      break;
    case ESP_AVRC_PT_CMD_PAUSE:
      Serial2.write((uint8_t*)"\xFFU\x04\x02\x00\x00\x02\xF8\xFFU\x03\x02\x00\x00\xFB", 15);
      break;
    case ESP_AVRC_PT_CMD_MUTE:
      Serial2.write((uint8_t*)"\xFFU\x04\x02\x00\x00\x04\xF6\xFFU\x03\x02\x00\x00\xFB", 15);
      break;
    case ESP_AVRC_PT_CMD_ROOT_MENU:
      Serial2.write((uint8_t*)"\xFFU\x05\x02\x00\x00\x00@\xB9\xFFU\x03\x02\x00\x00\xFB", 16);
      break;
    case ESP_AVRC_PT_CMD_SELECT:
      Serial2.write((uint8_t*)"\xFFU\x05\x02\x00\x00\x00\x80y\xFFU\x03\x02\x00\x00\xFB", 16);
      break;
    case ESP_AVRC_PT_CMD_UP:
      Serial2.write((uint8_t*)"\xFFU\x06\x02\x00\x00\x00\x00\x01\xF7\xFFU\x03\x02\x00\x00\xFB", 17);
      break;
    case ESP_AVRC_PT_CMD_DOWN:
      Serial2.write((uint8_t*)"\xFFU\x06\x02\x00\x00\x00\x00\x02\xF6\xFFU\x03\x02\x00\x00\xFB", 17);
      break;
    default:
      break;
  }

  Serial2.flush();
}

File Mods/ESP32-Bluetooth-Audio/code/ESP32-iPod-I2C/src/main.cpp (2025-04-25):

#include <Arduino.h>

#include "Wire.h"

#define I2C_PIN_SCL         21
#define I2C_PIN_SDA        22
// #define LED_PIN 23
// #define WAKE 21
// #define BTN_IN 22

#define I2C_DEV_ADDR 0x4A
#include "driver/periph_ctrl.h"

uint32_t i = 0;

void setup() {
  // pinMode(LED_PIN, OUTPUT);

  // for (int i = 0 ; i < 10; i++){
  //   digitalWrite(LED_PIN, i%2);
  //   delay(200);
  // }

  Serial.begin(115200);
  Serial.setDebugOutput(true);
  Wire.setClock(400000);
  Wire.setPins(I2C_PIN_SDA,I2C_PIN_SCL);
  // periph_module_disable(PERIPH_I2C0_MODULE);

  Wire.begin();

}

void loop() {
  delay(5000);

  // Write message to the slave
  Wire.beginTransmission(I2C_DEV_ADDR);
  Wire.write(0x04);
  uint8_t error = Wire.endTransmission(true);
  Serial.printf("Send Write: %u\n", error);

  uint8_t bytesReceived =  Wire.requestFrom(I2C_DEV_ADDR,1,true);

  Serial.printf("requestFrom: %u\n", bytesReceived);
  if ((bool)bytesReceived) {  //If received more than zero bytes
    uint8_t temp[bytesReceived];
    Wire.readBytes(temp, bytesReceived);
    log_print_buf(temp, bytesReceived);
  }
  delay(5000);

  // Set
  Wire.beginTransmission(I2C_DEV_ADDR);
  Wire.write(0x04);
  Wire.write(0x2A);
  error = Wire.endTransmission(true);
  Serial.printf("Send Write: %u\n", error);

}
